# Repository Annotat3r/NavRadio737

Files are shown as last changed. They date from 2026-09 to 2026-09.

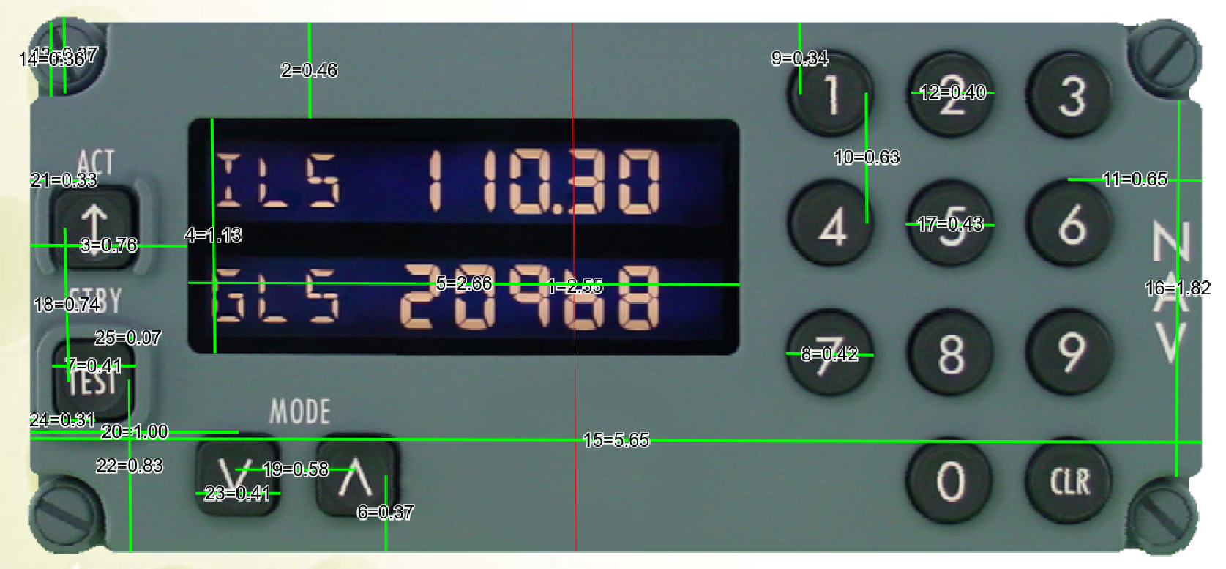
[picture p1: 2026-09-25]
CAD/References/Nav Panel Measured.png

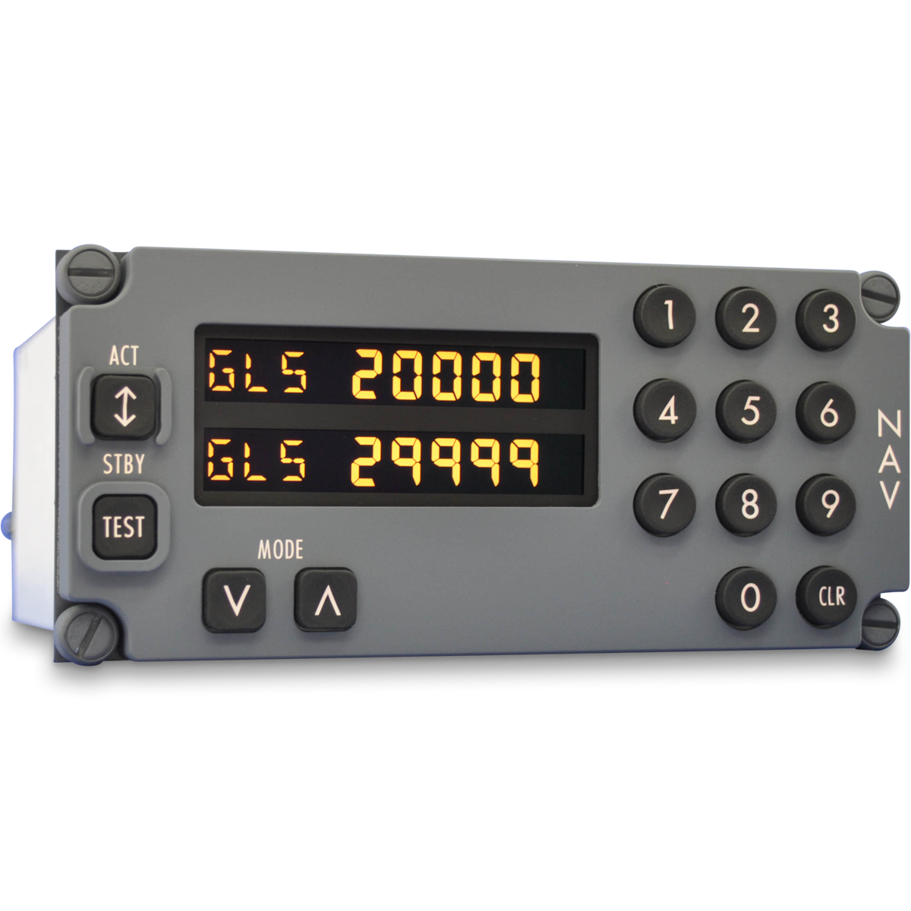
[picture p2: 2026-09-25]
CAD/References/Nav Radio 1.png

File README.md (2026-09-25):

MobiFlight Custom Device for the Boeing 737NG Multi-Mode Radio (MMR)

developed by Ryan Goff from the MF Community Device Template. It is

based on the Gables Engineering G7501-01 Boeing 737 Nav GLS Panel.

This project was developed for use with X-Plane 12 and the Zibo 

mod Boeing 737. The custom device code is written for the way 

X-Plane 12 outputs data for displaying on the LCD screen. I don't 

believe this code would work for MSFS without modifying.

CAD FILES

The CAD files include .stp (step) for all of the parts but it is important

to understand that I designed the parts with specific manufacturing

equipment in mind. The Acrylic and Plexiglass parts were cut using

a desktop cnc machine, spray painted, and then the text laser-engraved

using a blue-light diode laser.

The buttons were 3D printed using white filament, spray painted black,

and then laser engraved.

Because of the laser-engraving being a step that occurs later, the

CAD files for the faceplate and buttons do not include any text. The

text was added in the laser engraving software.

I have included 737NavRadio\_PCBA.step, which is a step file export of

the custom printed circuit board assembly.

PCBA

The PCBA features an on-board Raspberry Pi Pico (RP2040), making this

a fully self-contained device that requires no additional connections

to external microcontroller devices.

The backlighting is designed to operate off of an external 12V DC power

supply and does not work if only connected to 5V USB. If you are building

this panel and don't have, and don't want to acquire an external 12V

power supply, you will need to make edits to the schematic and board

files. Powering the backlighting from an external 12V source was done

to reduce the overall current requirements of the PCBA vs. powering

them from 5V. The backlighting is fully dimmable via connection to one

GPIO PWM pin through an N-Channel MOSFET.

Nearly all surface-mount devices on the PCB were ordered as part of the

PCB Assembly via jlcpcb.com. Through-hole components such as the 12V

power connection, the USB-Micro connector, 2-pin header for bootsel,

and 4-pin header for connecting the OLED display are user-soldered. All

push-buttons and LEDs on the PCB are user-soldered, though these are

SMT components.

The OLED display purchased must be a 2.42" 128x64 OLED LCD with I2C and

SSD1309 driver. The specific device I used in my build was from AliExpress

TZT 123 Official Store:

https://www.aliexpress.us/item/3256802580414312.html

Download the NavRadio737 custom device and move it to your MF Community

folder directory. Use the RP2040 pin connections shown in the schematic

to set up your mobiflight input/output devices.

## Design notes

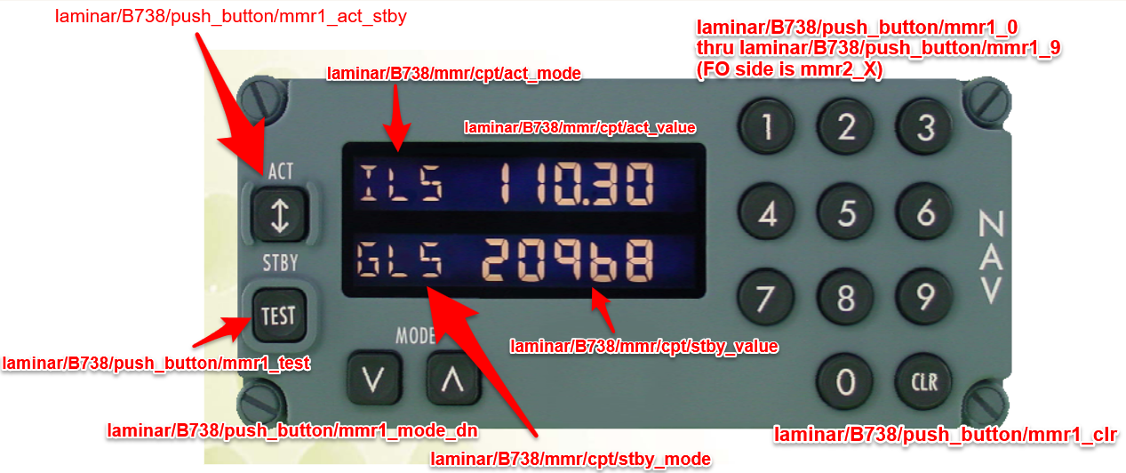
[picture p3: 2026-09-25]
CAD/References/Nav Radio Datarefs.png

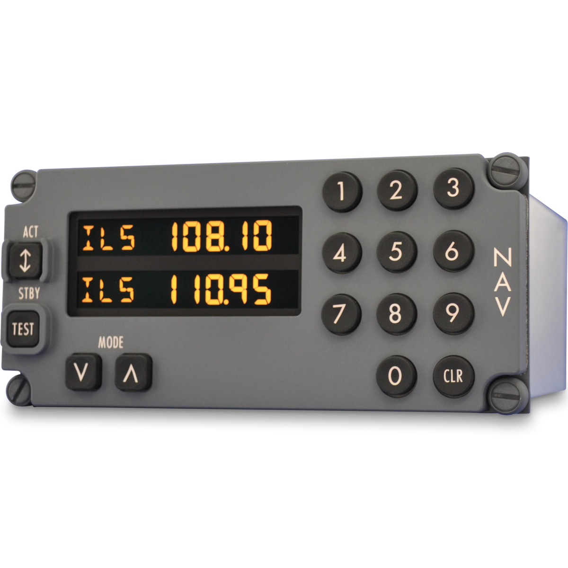
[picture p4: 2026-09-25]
CAD/References/Nav Radio 2.png

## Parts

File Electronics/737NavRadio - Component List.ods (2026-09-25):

Reference | Value | Source & Part Number | Footprint | Qty
C1,C5 | 33pF | https://www.lcsc.com – C1663, 33pF ceramic capacitor, 50V, 0603 SMT | PCM_JLCPCB:C_0603 | 2
C2,C3,C6,C7,C8,C9,C10,C11,C12,C13,C17 | 100nF | https://www.lcsc.com - C307331, 100nF ceramic capacitor, 50V, 0402 SMT | PCM_JLCPCB:C_0402 | 11
C4,C14 | 1uF | https://www.lcsc.com - C52923, 1uF ceramic capacitor, 25V, 0402 SMT | PCM_JLCPCB:C_0402 | 2
C15,C16 | 10uF | https://www.lcsc.com - C96446, 10uF ceramic capacitor, 25V, 0603 SMT | PCM_JLCPCB:C_0603 | 2
D1,D2 | SS14 | https://www.lcsc.com - C2480, 40V Schottky Diode DO-214AC | PCM_JLCPCB:D_SMA | 2
D3,D4,D5,D6,D7,D8,D9,D10,D11,D12,D13,D14,D15,D16,D17,D18,D19,D20,D21,D22 | 2.0Vf, 20mA If | Www.digikey.com - Würth Elektronik, 150080AS75000, LED AMBER CLEAR 0805 SMD | LED_SMD:LED_0805_2012Metric | 20
J1 | Conn_01x02 | www.digikey.com - PRPC002SAAN-RC, vertical connector header, 2.54mm pitch | Connector_PinHeader_2.54mm:PinHeader_1x02_P2.54mm_Vertical | 1
J2 | USB3131-30-0230-A | Www.digikey.com - USB3131-30-0230-A, micro B USB connector | SamacSys_Parts:CONN_USB3131-30-0230-A_GCT | 1
J3 |  | www.digikey.com - B2B-XH-A, 2.54mm JST connector | SamacSys_Parts:JST_B2B-XH-A | 1
J4,J5,J6,J7,J8,J9,J10,J11,J12,J13,J14,J15,J16,J17,J18 |  | www.digikey.com - KSC241J LFS, tactile switches | KSC241JDCTLFS | 15
J19 | Conn_01x04_Pin | www.digikey.com - NRPN041PAEN-RC, vertical connector header, 2.54mm pitch | Connector_PinHeader_2.54mm:PinHeader_1x04_P2.54mm_Vertical | 1
Q1 | AO3400A | https://www.lcsc.com - C20917, MOSFET, N-Channel, 30V, SOT-23 | PCM_JLCPCB:Q_SOT-23 | 1
R1,R6 | 1kΩ | https://www.lcsc.com - C21190, 100mW, 0603 SMT | PCM_JLCPCB:R_0603 | 2
R2,R3 | 27Ω | https://www.lcsc.com - C25190, 100mW, 0603 SMT | PCM_JLCPCB:R_0603 | 2
R4 | 1k | https://www.lcsc.com - C11702, 62.5mW, 0402 SMT | PCM_JLCPCB:R_0402 | 1
R5 | DNF | Do Not Fit (DNF), no device soldered here unless certain adverse device behavior exists (rare) | Resistor_SMD:R_0805_2012Metric | 1
R7 | 10kΩ | https://www.lcsc.com - C25804, 100mW, 0603 SMT | PCM_JLCPCB:R_0603 | 1
R8,R9,R10,R11 | 120Ω | https://www.lcsc.com - C22787, 100mW, 0603 SMT | PCM_JLCPCB:R_0603 | 4
U1 | RP2040 | https://www.lcsc.com - C2040, Raspberry Pi RP2040 MCU | PCM_JLCPCB:QFN-56-1EP_7x7mm_P0.4mm_EP3.2x3.2mm_ThermalVias | 1
U2 | W25Q128JVSIQ | https://www.lcsc.com - C97521, 128M-Bit Serial Flash Memory | PCM_JLCPCB:SOIC-8_L5.3-W5.3-P1.27-LS8.0-BL | 1
U3 | AMS1117 | https://www.lcsc.com - C6186, 1A LDO 3V Regulator | PCM_JLCPCB:SOT-223-3_L6.5-W3.4-P2.30-LS7.0-BR | 1
X1 | X322512MSB4SI | https://www.lcsc.com - C9002, 12MHz 20pF Crystal Oscillator | PCM_JLCPCB:CRYSTAL-SMD_4P-L3.2-W2.5-BL | 1

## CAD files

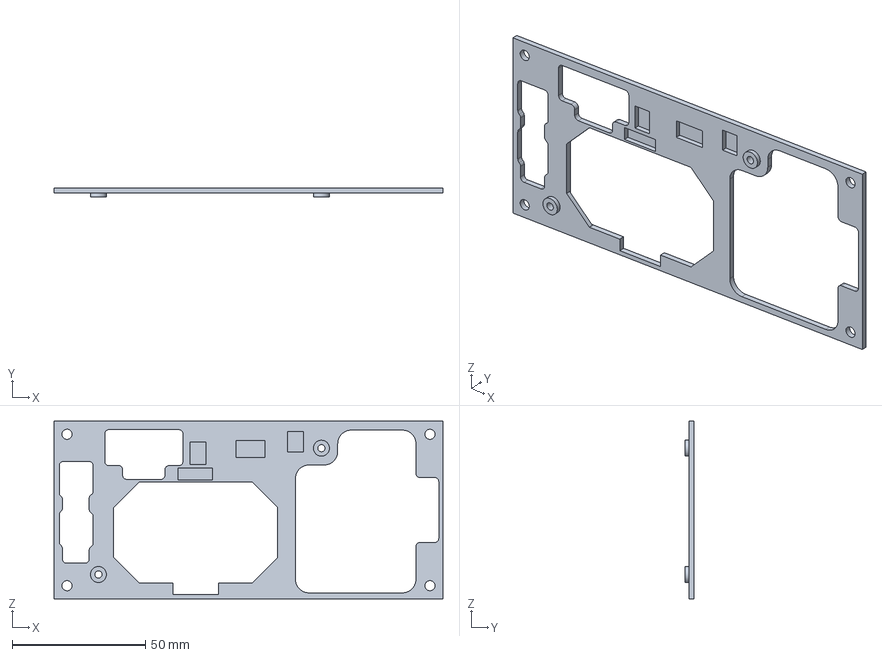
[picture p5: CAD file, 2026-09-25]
CAD/Nav Panel Backplate.stp
146.0 x 3.50 x 66.7 mm

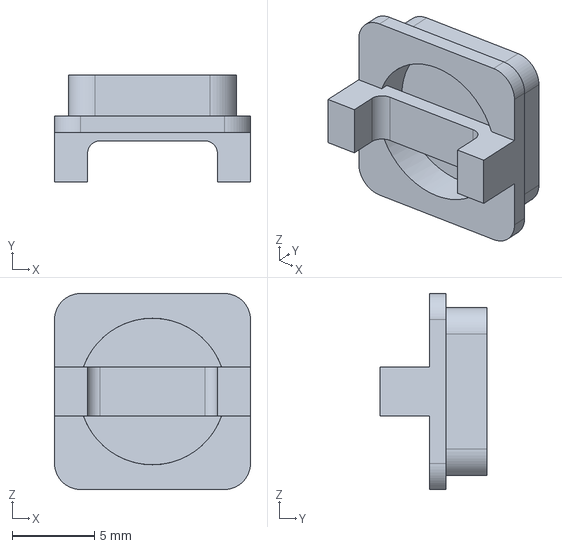
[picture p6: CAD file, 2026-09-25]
CAD/Square Button.stp
11.9 x 6.50 x 11.9 mm

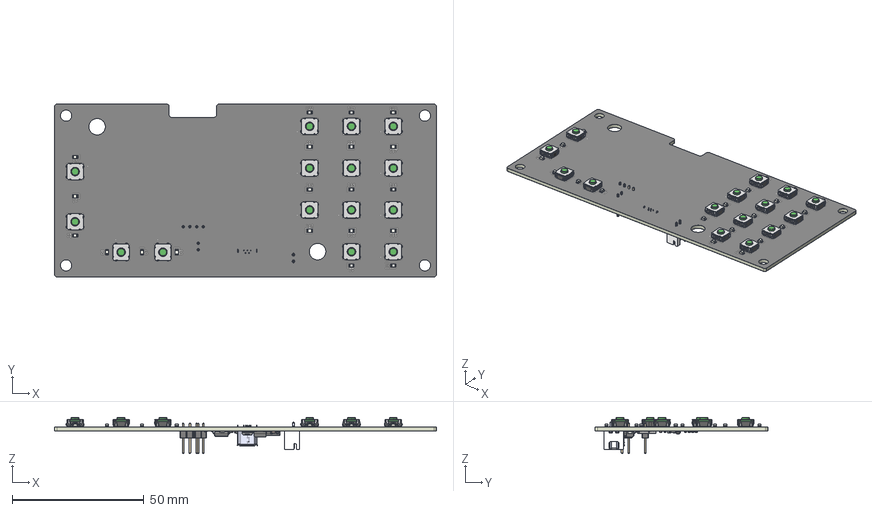
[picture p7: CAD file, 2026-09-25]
CAD/737NavRadio_PCBA.step
145.0 x 65.7 x 13.7 mm
KSC241J_DCT_LFS x 15
LED_0805_2012Metric x 20
C_0402 x 13
BxB-XH-A_02
PinHeader_1x04_P2.54mm_Vertical
R_0603 x 9
R_0805_2012Metric
PinHeader_1x02_P2.54mm_Vertical
C_0603 x 4
SOIC-8_L5.3-W5.3-P1.27-LS8.0-BL
SOT-223-3_L6.5-W3.4-P2.30-LS7.0-BR
Q_SOT-23
CRYSTAL-SMD_4P-L3.2-W2.5-BL
D_SMA x 2
R_0402
USB3131-30-0230-A
QFN-56-1EP_7x7mm_P0.4mm_EP3.2x3.2mm
737NavRadio_silkscreen x 2
737NavRadio_soldermask x 2
737NavRadio_PCB

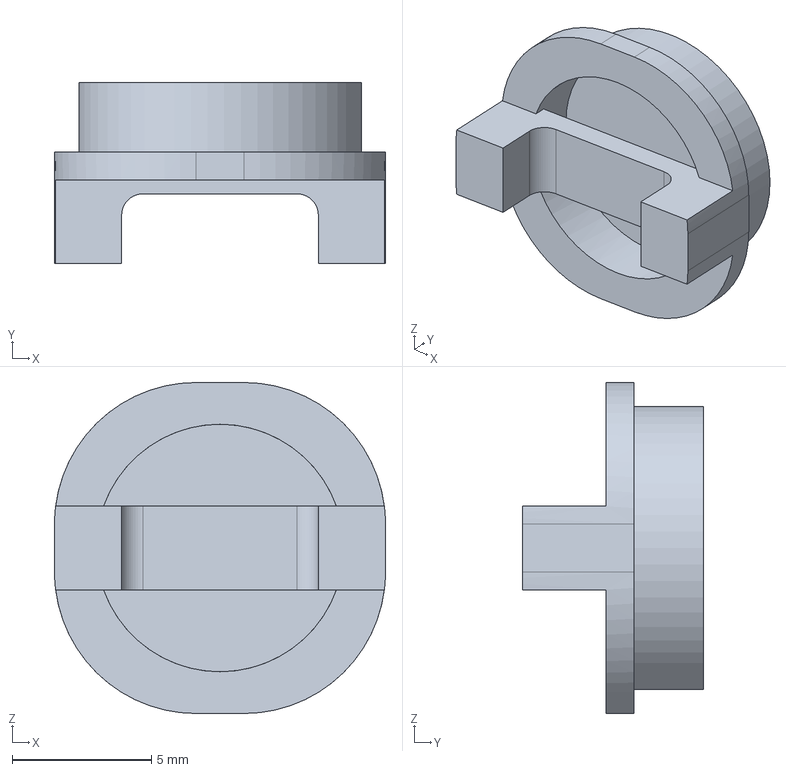
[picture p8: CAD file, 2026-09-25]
CAD/Round Button.stp
11.9 x 6.50 x 11.9 mm

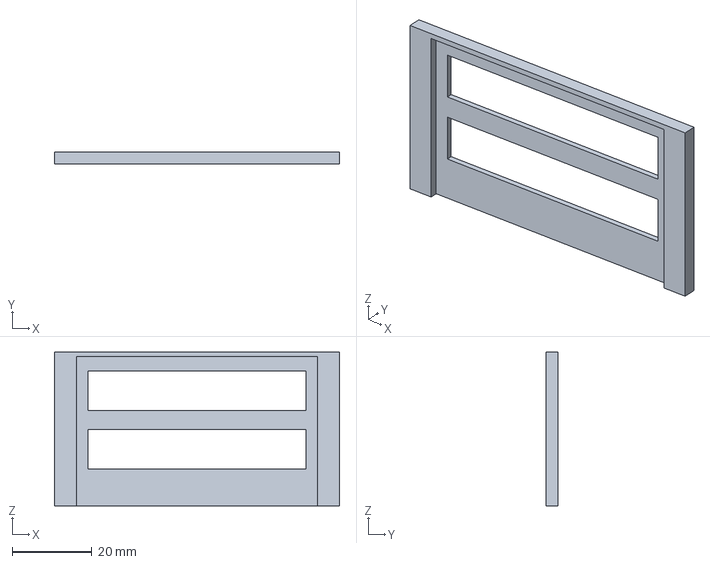
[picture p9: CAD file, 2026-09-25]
CAD/OLED Cover.stp
71.5 x 2.95 x 38.6 mm

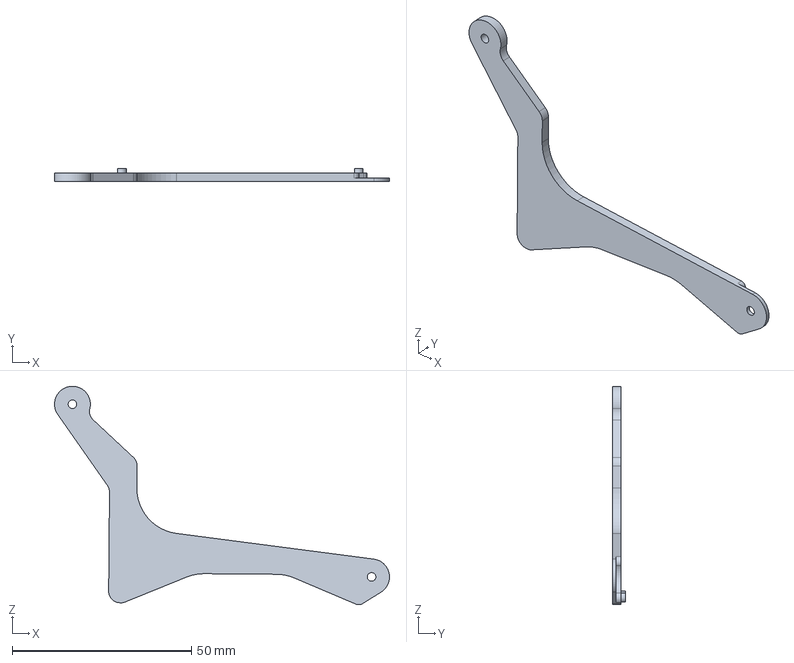
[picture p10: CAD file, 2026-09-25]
CAD/Main PCBA Washer.stp
93.3 x 3.75 x 60.9 mm

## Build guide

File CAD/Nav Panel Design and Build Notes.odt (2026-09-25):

Gables G7501-01 B737 Nav GLS Panel

https://www.gableseng.com/product/nav-gls-2/

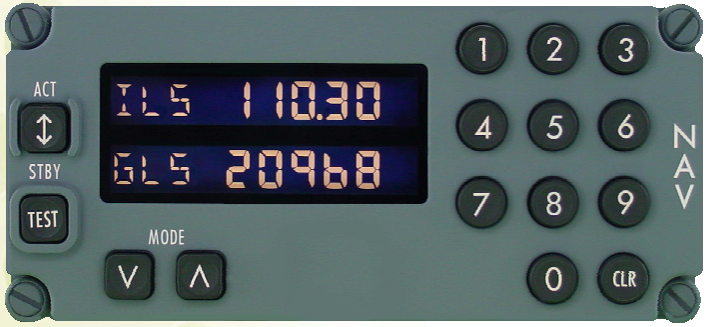
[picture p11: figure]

# Panel Sizing

Overall dimensions: 2.625” Height x 5.75” Wide (for the backplate). Based on the document “DZUS Rhythm” we know that the DSUZ fasteners are spaced in multiples of 3/8” (0.375”), so we can extrapolate that the fasteners here are at 2.25” apart center to center.

All panels in the center pedestal are 5.75” wide (width of the aluminum backplate).

The Faceplate typically is 1/32” smaller all the way around (1/16 overall), so 2.625 - .03125 Height x 5.75 - .03125 Wide. This comes out to a faceplate size of 2.59375” Height x 5.71875” Wide.

The center to center dimensions for the DZUS fasteners are 2.25” vertically, and 5.375” horizontally.

“Aluminum” backplate dimensions: 2.61” vertically, and 5.735” horizontally.

# The OLED Display

This 2.42” 128x64 OLED LCD SSD1309 Display (https://www.aliexpress.us/item/3256802580414312.html?curPageLogUid=d27N1Zjv7QwT) appears as though it would fit the display opening quite nicely. Here’s a screen grab of the dimensional information:

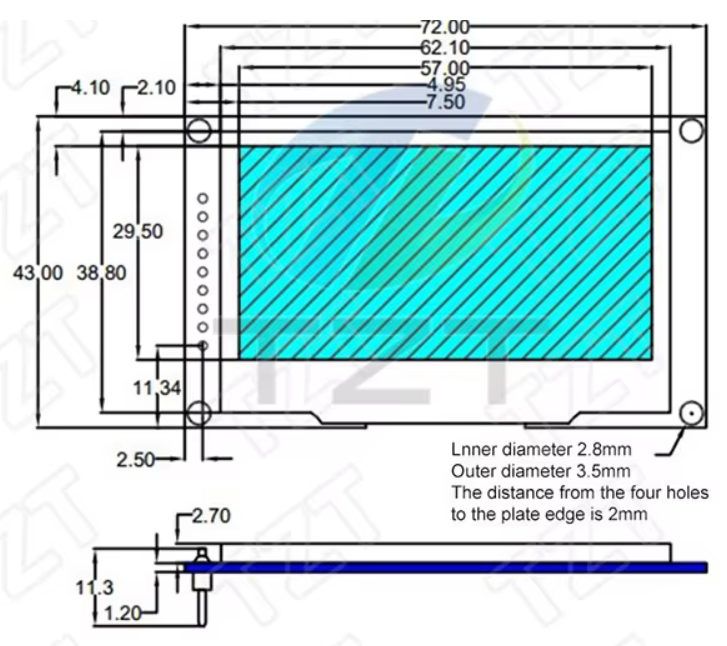
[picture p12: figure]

As can be seen, the display (viewable area) measures 2.244” wide x 1.16” tall. The discrepancies between the display size and the opening size can be filled with 3D printed bezel.

# Planning the Custom Device

In terms of a first custom device program, this one should be fairly easy.

I will need:

- A font that looks like 7-segment displays - Complete
- To create custom characters for the following: VOR, ILS, GLS, LVP
- On-board RP2040 design
- The only output is the display
- 15 button inputs.
- Ability for screen to go dark via MF sim dataref.
  - Maybe control screen power via another GPIO?
  - Maybe use the U8g2.setPowerSave(1) and (0) command?
  - This screen does not appear to support u8g2.setContrast(value).

## Simulator Integration

The nav radio in the zibo appears to be referred to as the “mmr”. Datarefs are tied to mmr.

laminar/B738/mmr/cpt/act_value for example is the dataref for the captain’s mmr active frequency value.

Datarefs below are untested:


## Code Considerations for Formatting the Display

### Active Frequency Formatting

ILS & VOR frequencies display a decimal point. GLS/LVP do not. Between VOR & ILS, the greatest frequency value is roughly 117.50Mhz. Specify formatting of sim value based on this. If statement, value greater than 12000 no decimal.

### Standby Frequency Display & Formatting

The dataref for the standby frequency displays the entries

## Display Information

The display I purchased uses I2C protocol.

Chip: SSD1309

4-Pin Connection
1 GND
2 VDD (3.3V)
3 SCL (Clock)
4 SDA (Data)

The address of the display appears to be 0x3C * 2, or 0x78 (in hex).

This is a 3.3V display. 128 x 64 pixels.

Each pixel is 0.4mm (0.0157”) square. The pitch of the pixels (distance from top of one pixel to top of next pixel) is 0.43mm (0.0169”).

If typical digit size for cockpit panels is 0.36”, my text height should be (.36” / .0169”) = 21 pixels. This actually works out to a digit height of .3549”. This will be a starting point and may need tweaked depending on visual preference.

Display “active” area is 55.02mm (2.166”) wide x 27.5mm (1.083”) tall.

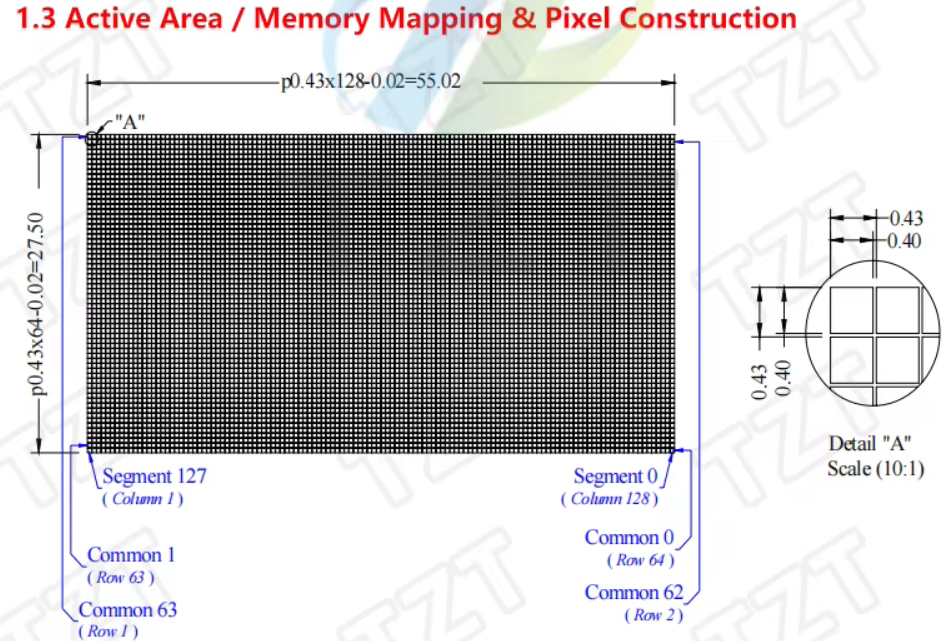
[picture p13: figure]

# The Code

## Helpful Notes for designing the Code

In the C++, note that calling out pins is referring to the GPIO number of the RP2040, NOT the actual device pin number! Example: Wire.setSDA(4); means SDA is connected to GPIO4, which is actually pin 6.

In the U8g2 library, text coordinates refer to the baseline (the bottom) of the text, not the top. If you draw at y = 0, your text will be off-screen. Usually, you start at y = 10 for the top line.

# Notes for the Electronics

Illuminated white tactile switches are aliexpress versions of the TS29-1212-1-WT-300-D switches by Same Sky. Vf = 3.2V typ. If = 20mA typ. Marked leg on LED is the cathode pin (short pin, negative).

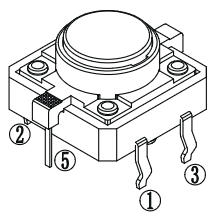
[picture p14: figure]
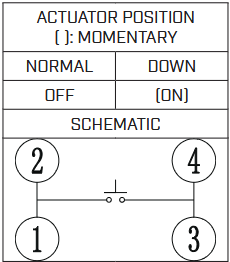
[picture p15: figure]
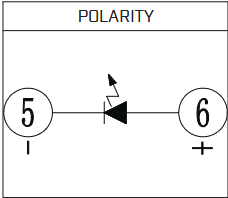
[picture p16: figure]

# Things Left To Do

Add 4-pin 2.54mm pitch header for connecting OLED to main PCBA. Determine what the connection method between these two boards will be.

Add mounting holes in PCB to attach to panel back plate.

Determine LEDs for the minimal backlighting of panel text.

Find a solution to opening in back plate behind the “MODE” text.

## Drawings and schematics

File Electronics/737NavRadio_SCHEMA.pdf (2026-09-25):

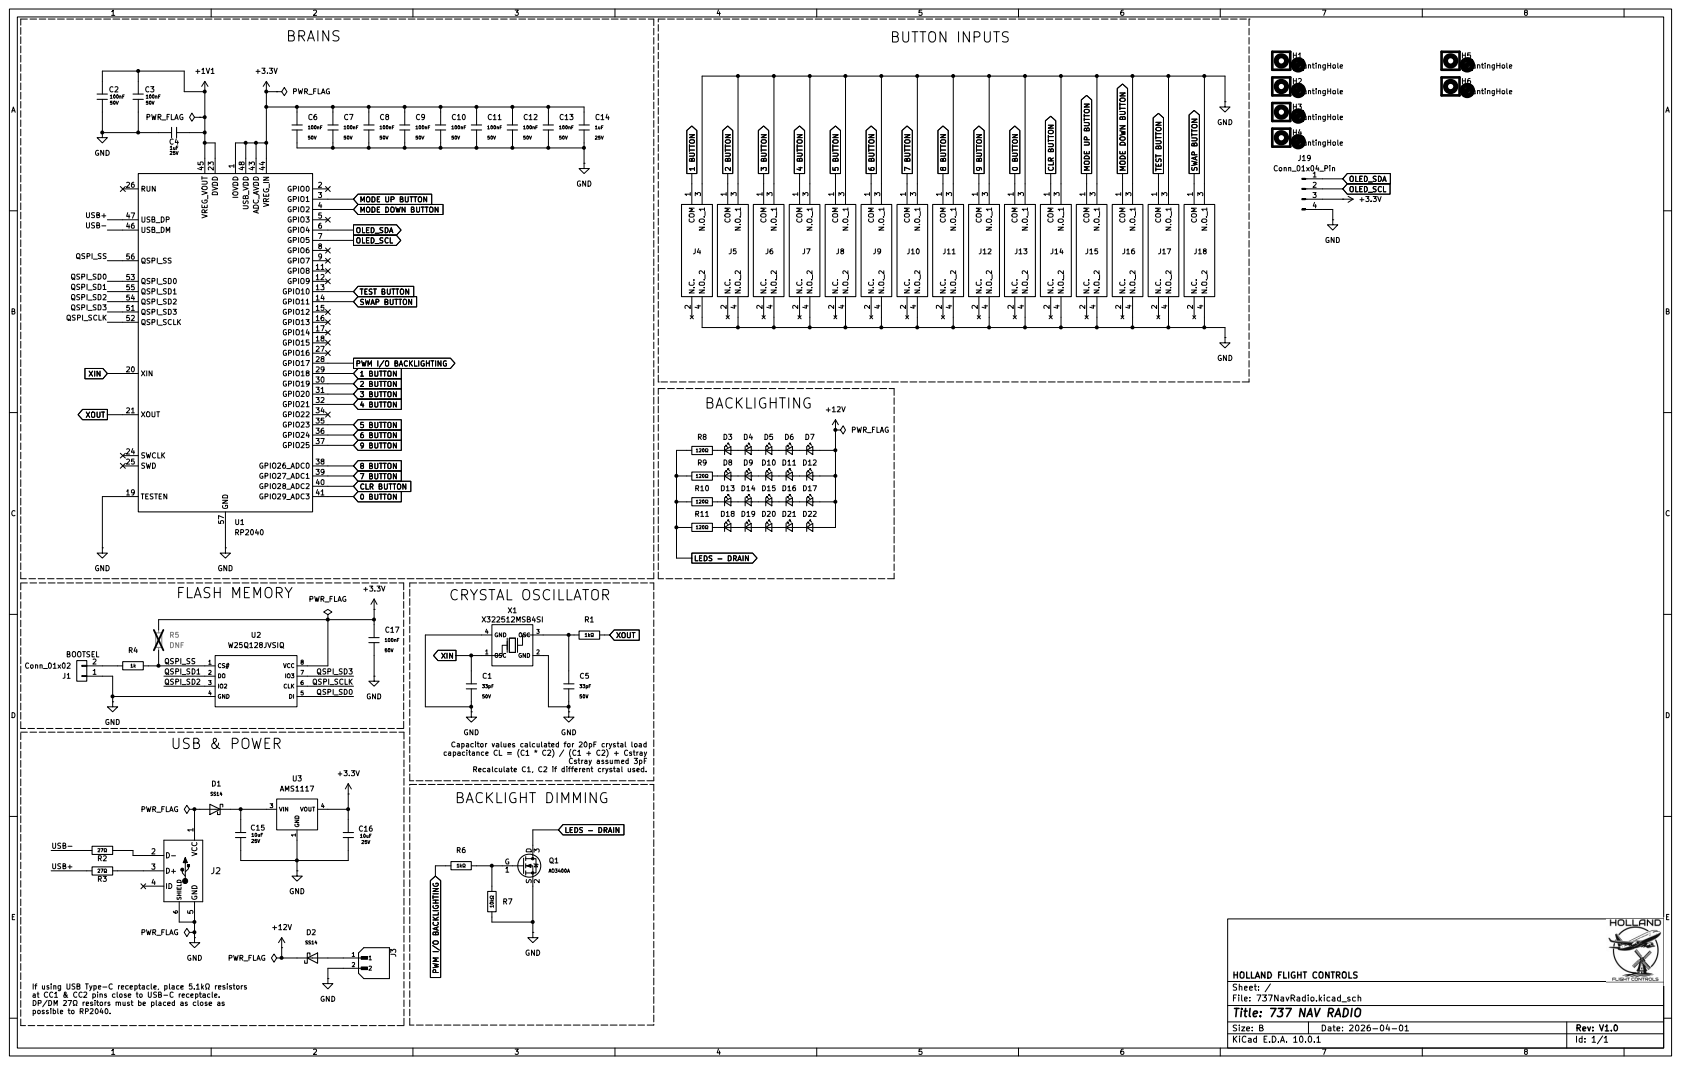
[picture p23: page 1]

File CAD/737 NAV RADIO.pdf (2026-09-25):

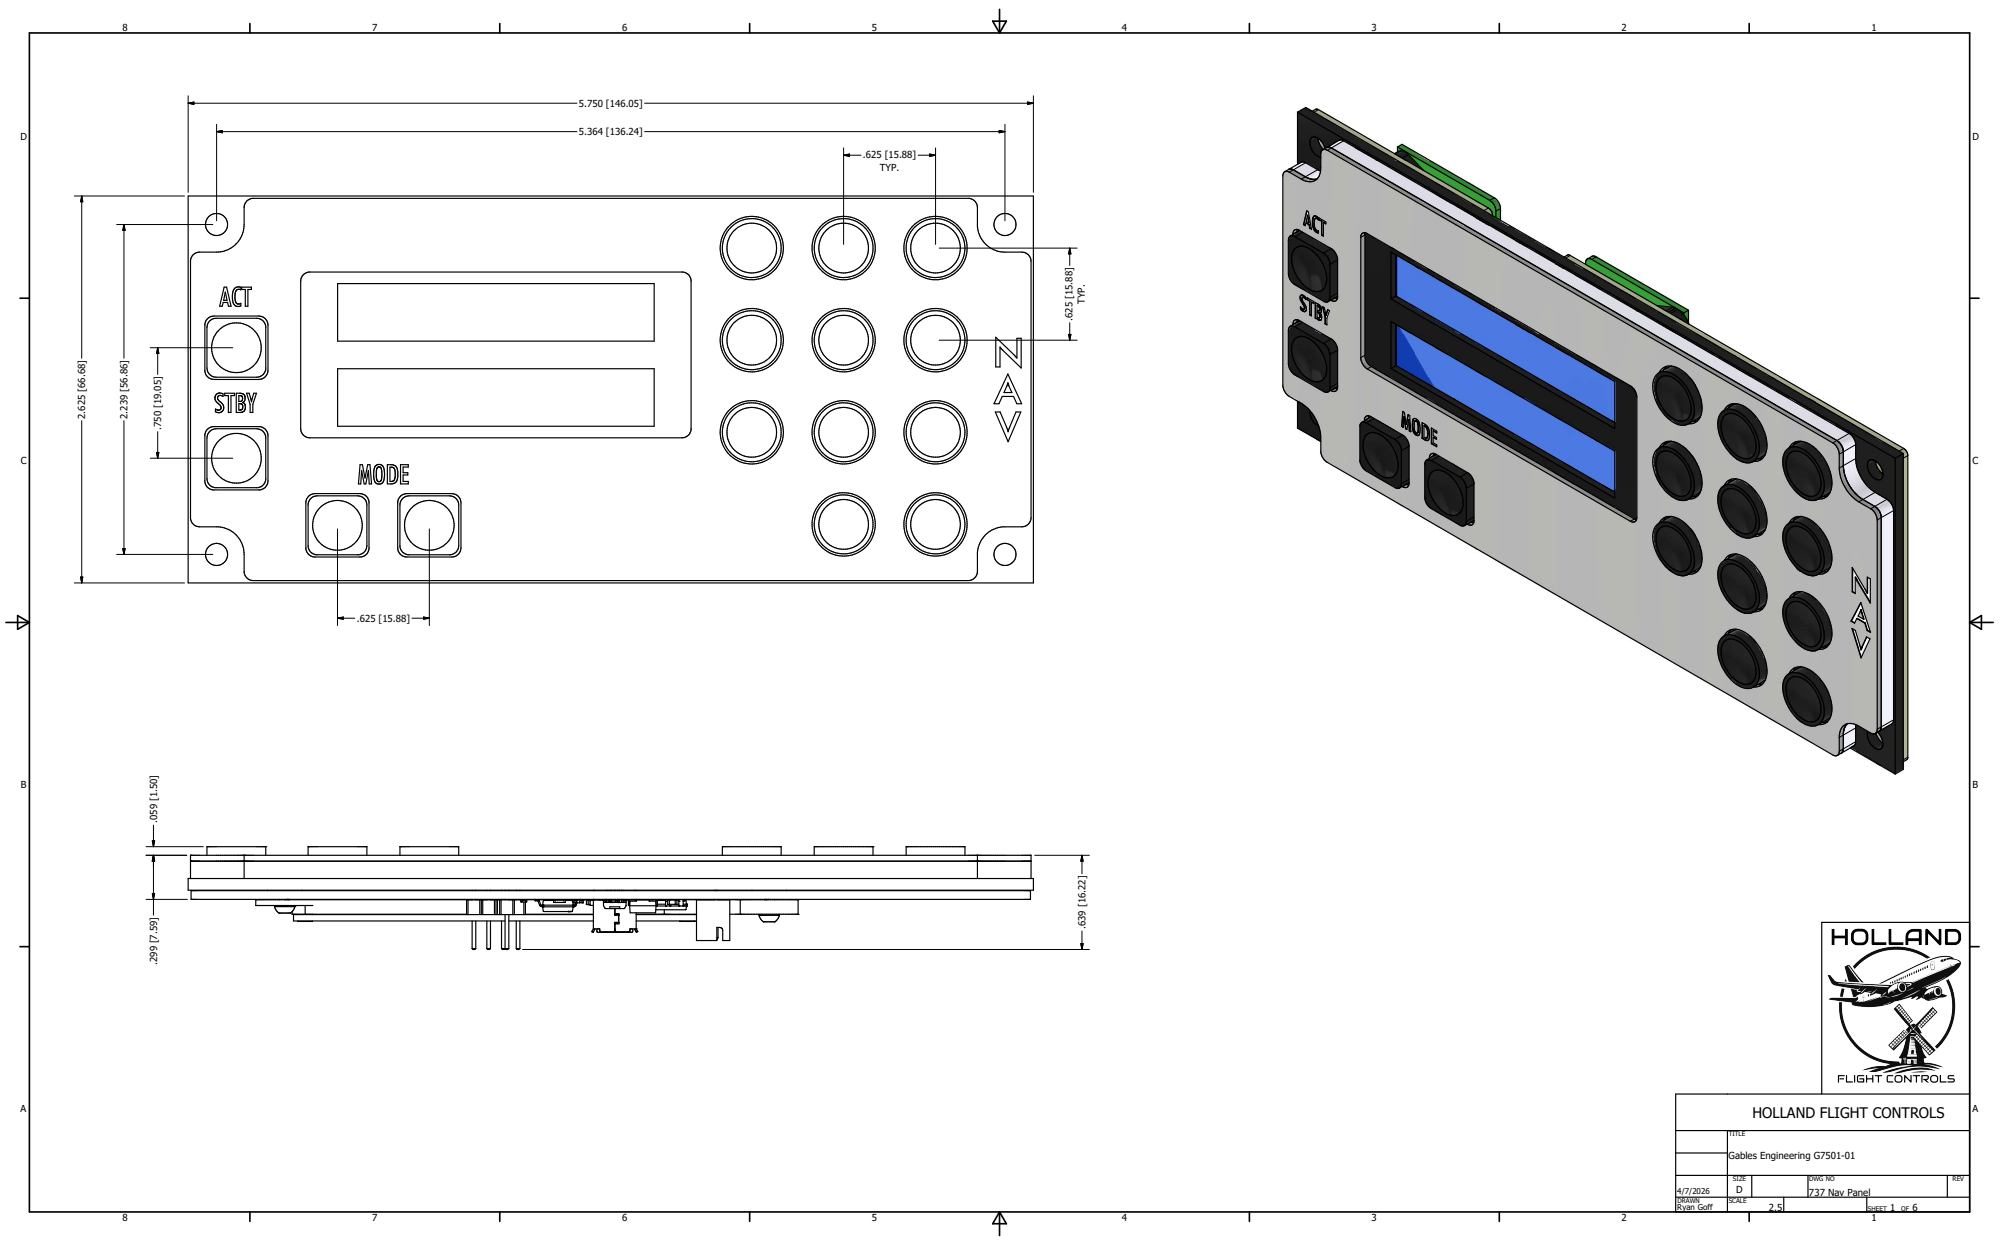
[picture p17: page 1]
DRAWN Ryan Goff; SCALE; DWG NO; 737 Nav Panel; REV; SHEET 1 OF 6 ².625 [66.68]; .625 [15.88] TYP.; .625 [15.88] TYP. .299 [7.59] .059 [1.50]

HOLLAND FLIGHT CONTROLS TITLE Gables Engineering G7501-01 SIZE D

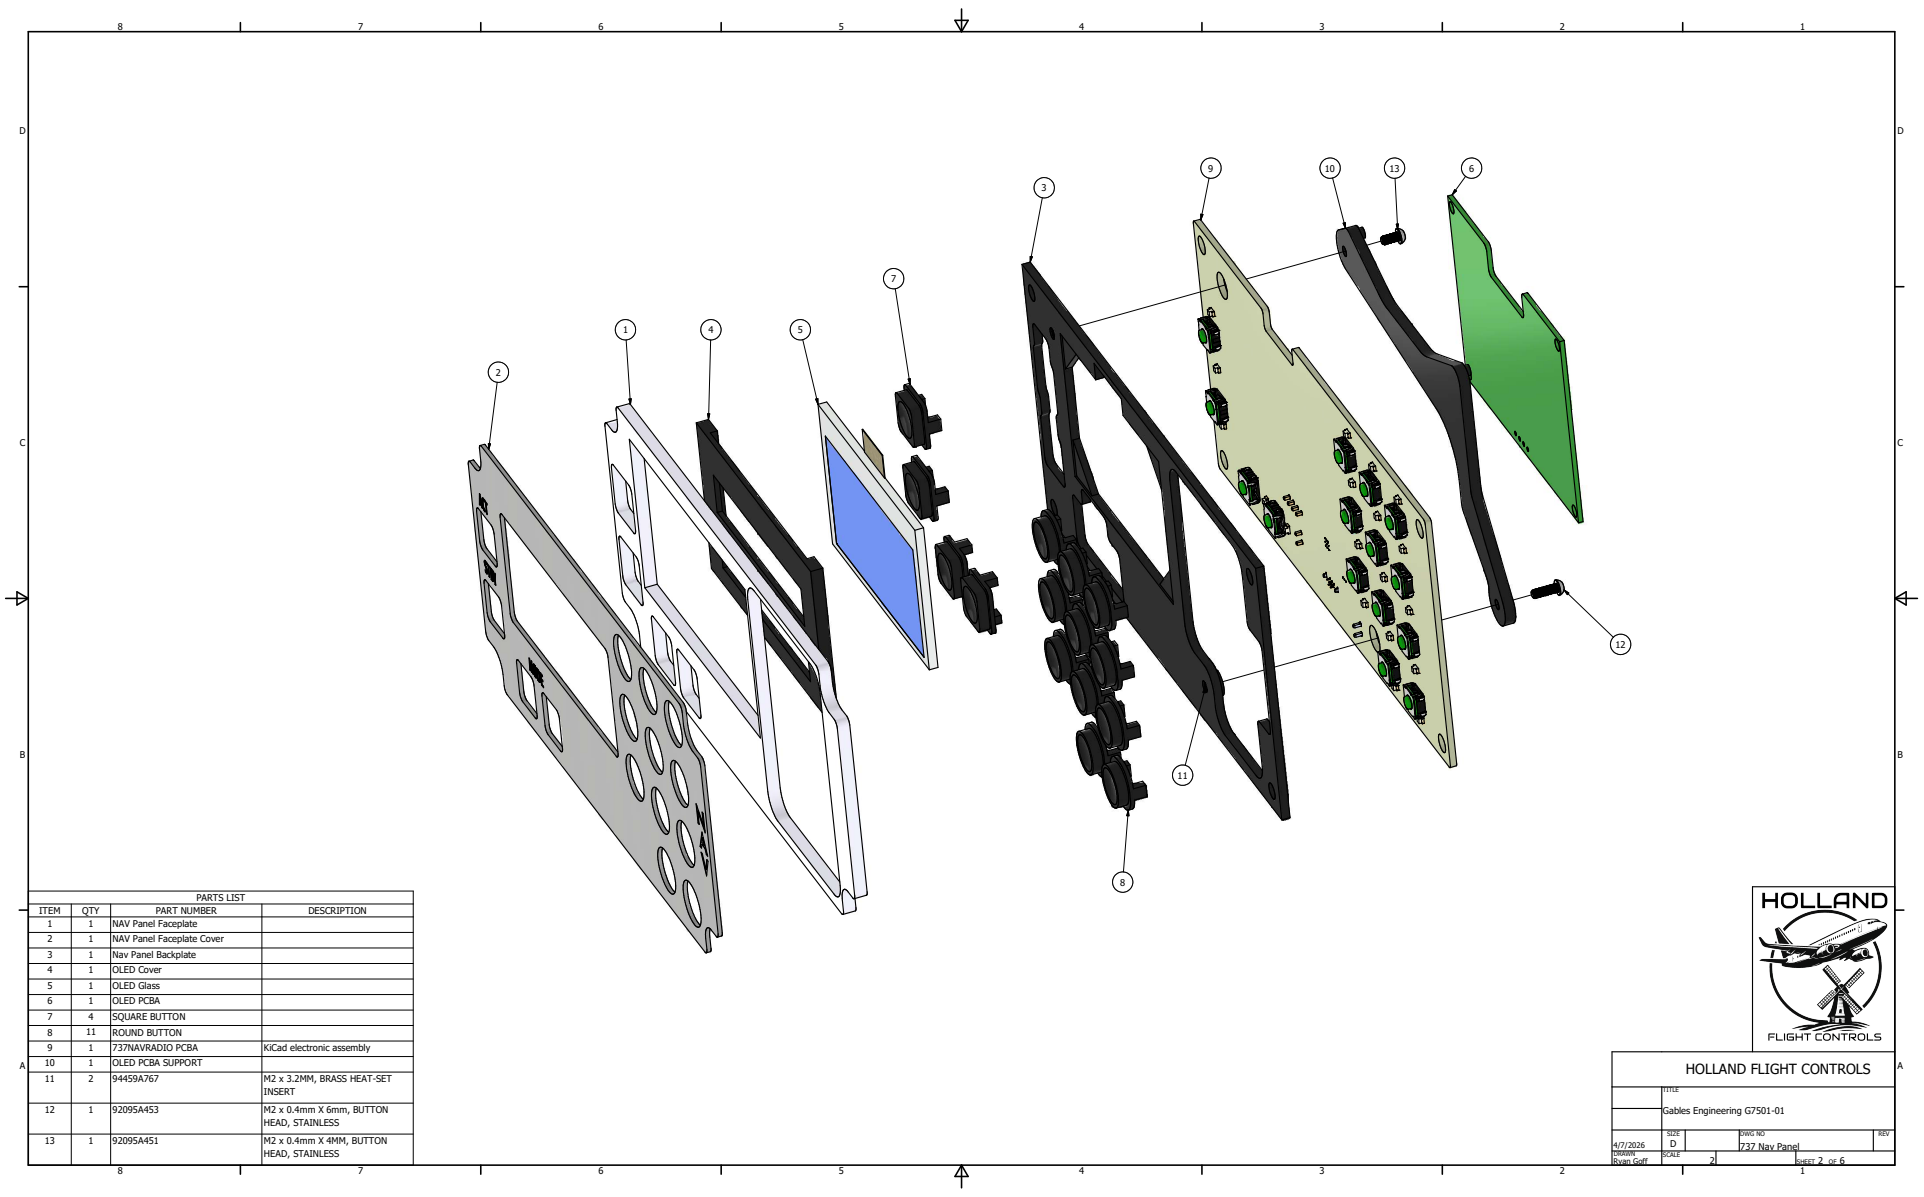
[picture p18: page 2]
2 SHEET 2 OF 6; PARTS LIST; ITEM; QTY; PART NUMBER; DESCRIPTION; NAV Panel Faceplate 2; NAV Panel Faceplate Cover; Nav Panel Backplate 4; OLED Cover 5; OLED Glass; OLED PCBA; SQUARE BUTTON; ROUND BUTTON; 737NAVRADIO PCBA; KiCad electronic assembly; OLED PCBA SUPPORT

HOLLAND FLIGHT CONTROLS TITLE Gables Engineering G7501-01 SIZE D

M2 x 3.2MM, BRASS HEAT-SET
INSERT
M2 x 0.4mm X 6mm, BUTTON
HEAD, STAINLESS
M2 x 0.4mm X 4MM, BUTTON

# HEAT PRESS THREADED BRASS INSERTS INTO

REAR OF BACKPLATE, (2) PLCS. | ASSEMBLY OF THE NAVIGATION RADIO REQUIRES

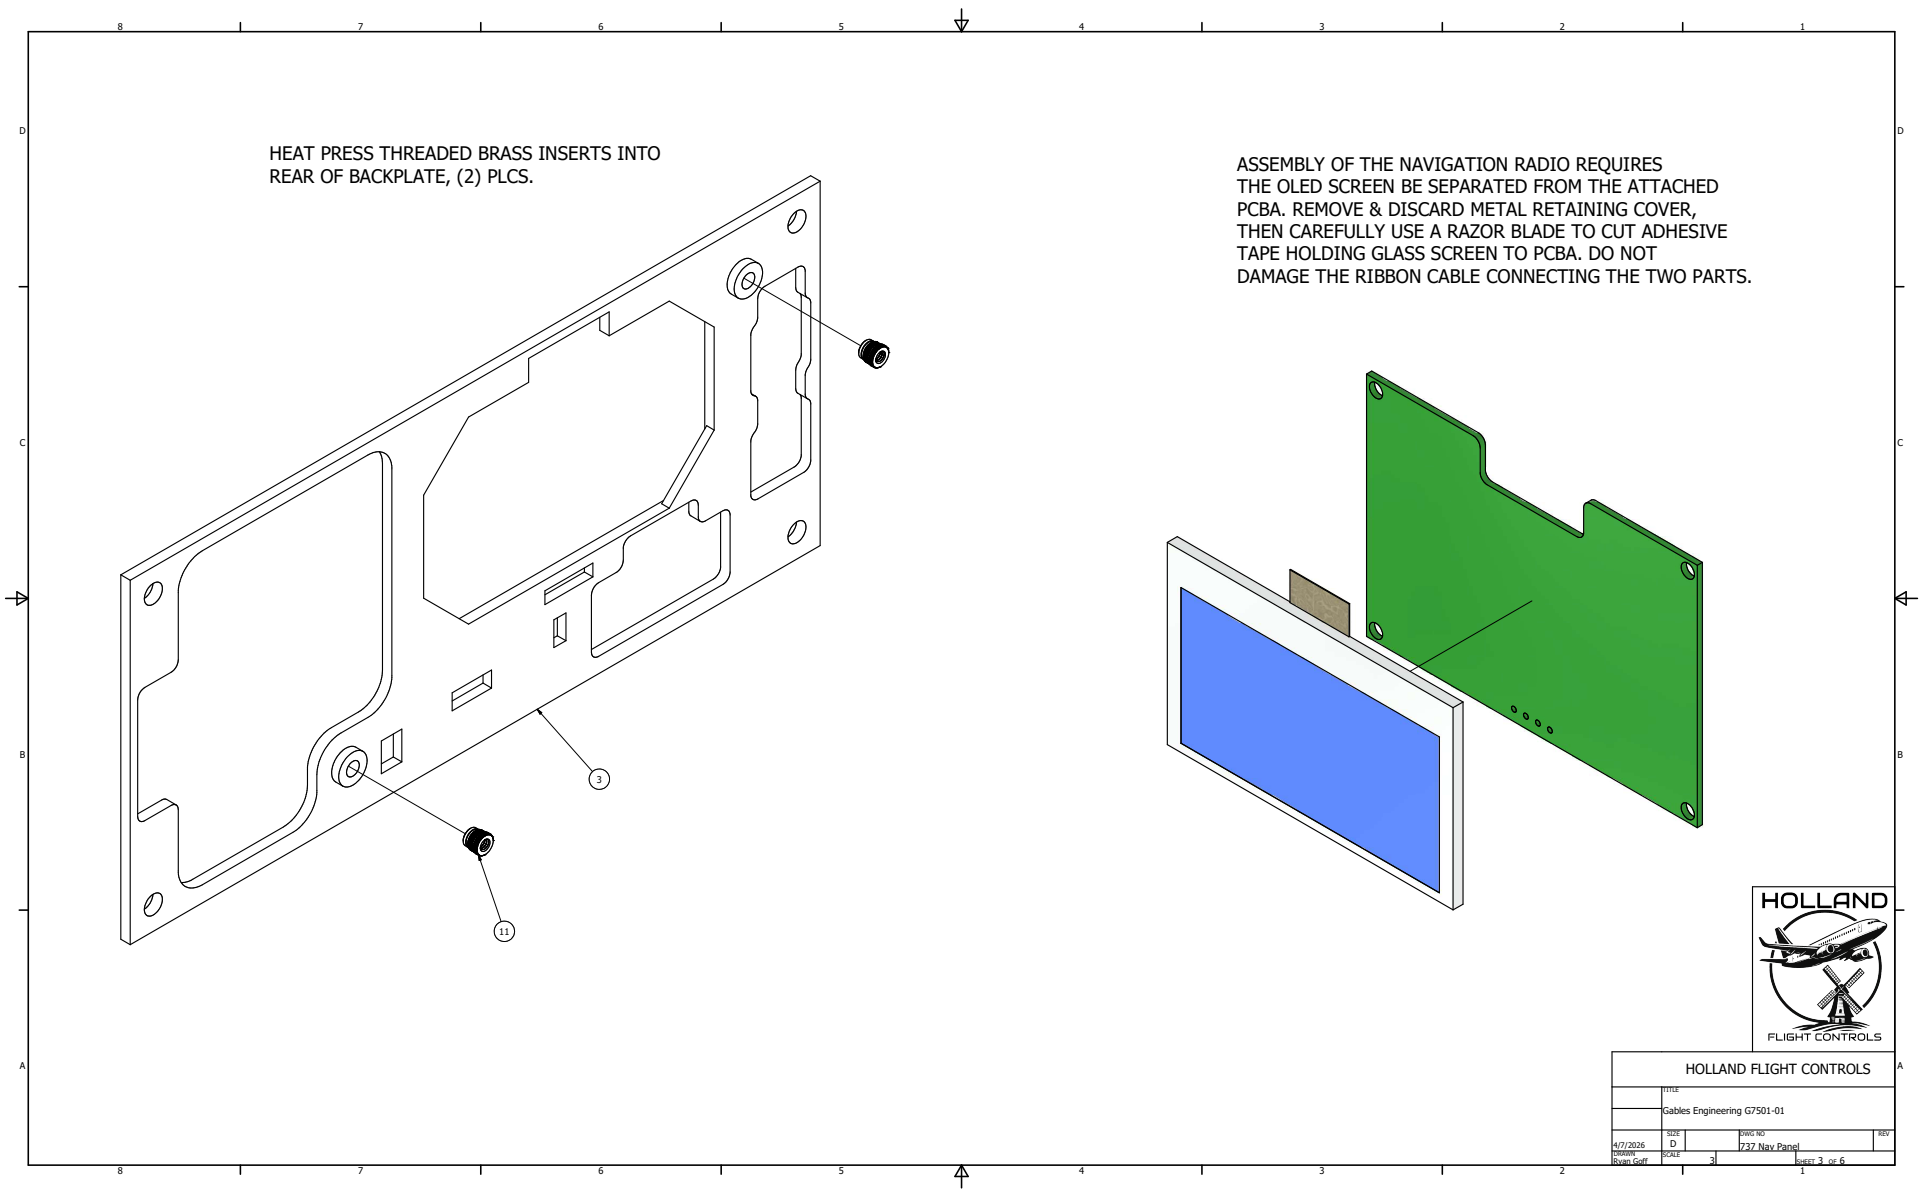
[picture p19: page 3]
3 SHEET 3 OF 6

THE OLED SCREEN BE SEPARATED FROM THE ATTACHED
PCBA. REMOVE & DISCARD METAL RETAINING COVER,
THEN CAREFULLY USE A RAZOR BLADE TO CUT ADHESIVE
TAPE HOLDING GLASS SCREEN TO PCBA. DO NOT
DAMAGE THE RIBBON CABLE CONNECTING THE TWO PARTS.

HOLLAND FLIGHT CONTROLS TITLE Gables Engineering G7501-01 SIZE D

# GLUE FACEPLATE COVER, FACEPLATE & BACK PLATE TOGETHER AFTER

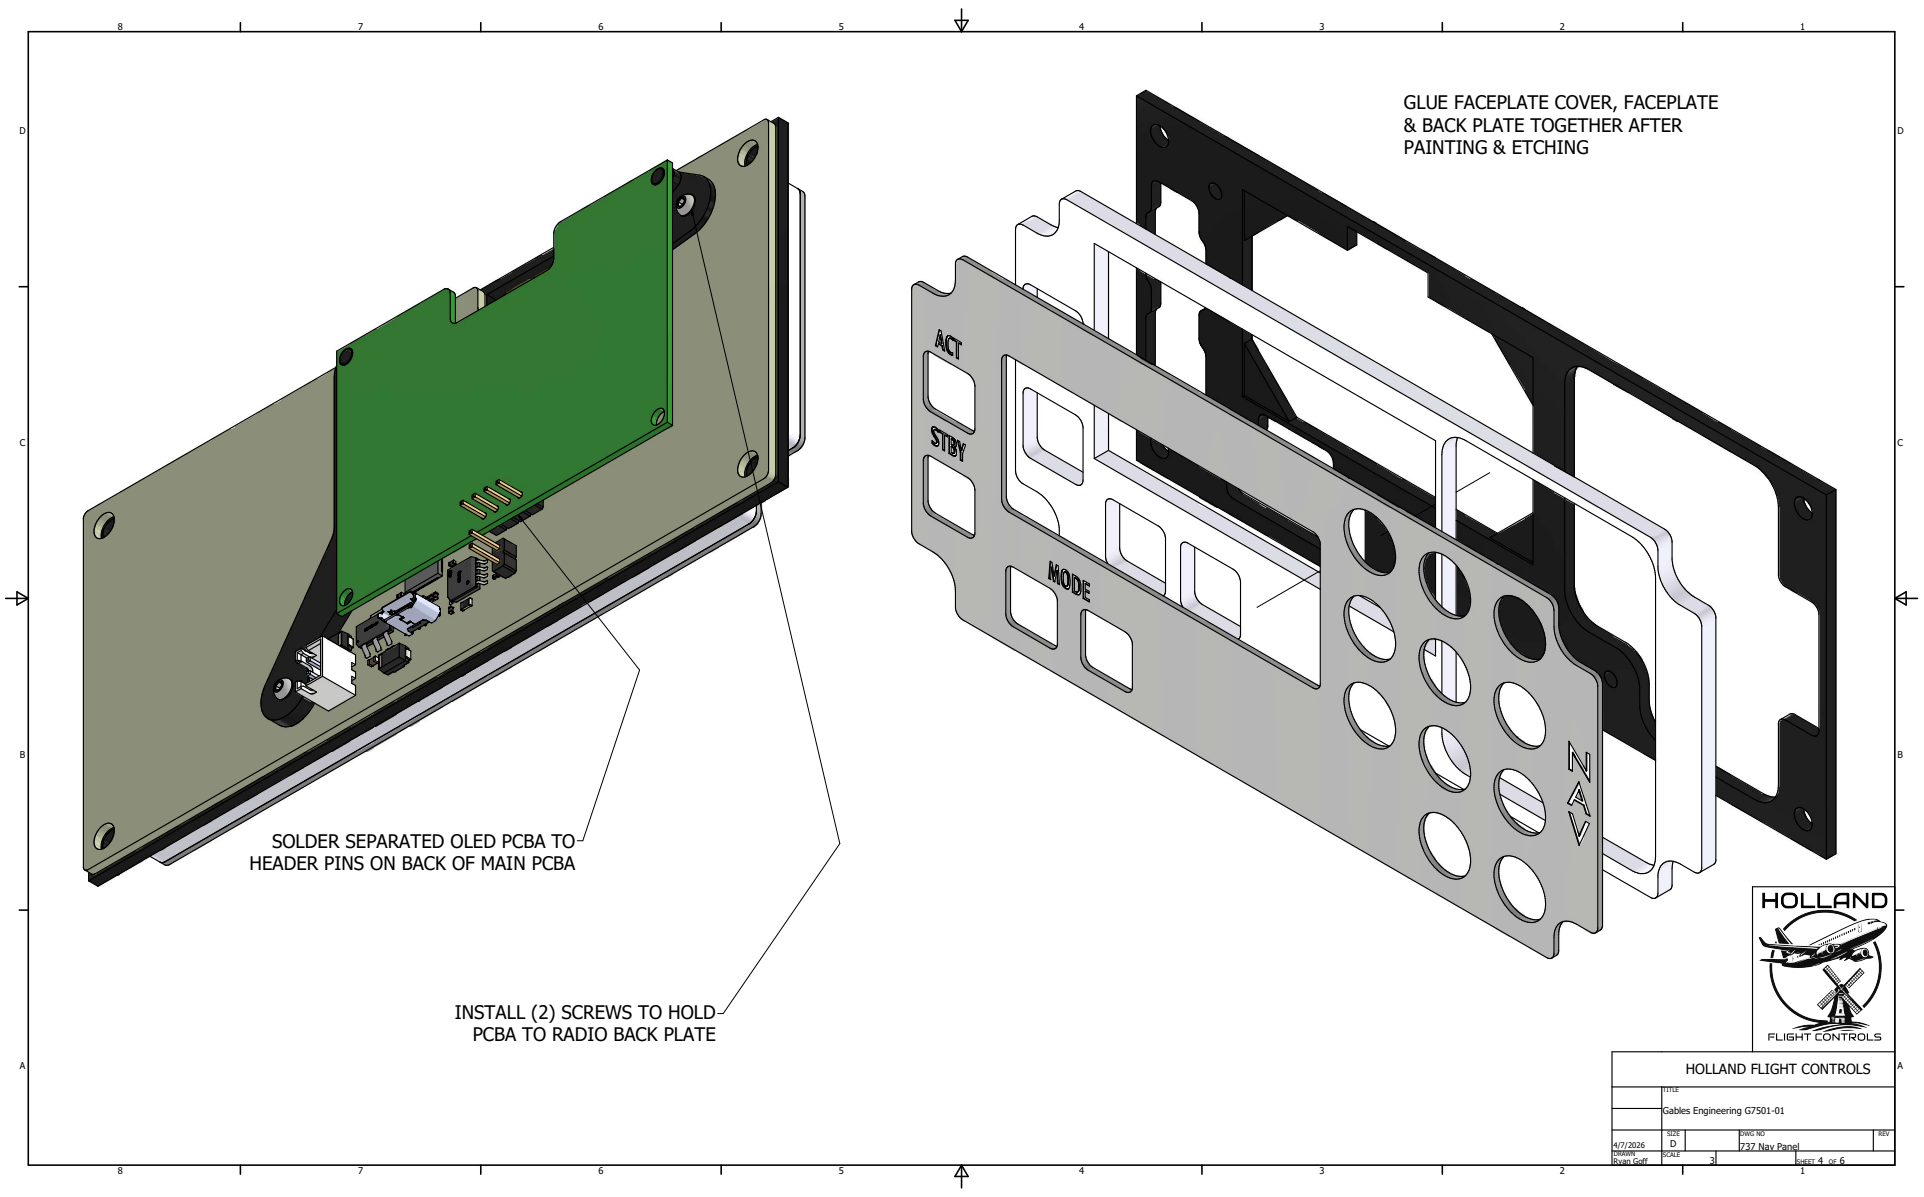
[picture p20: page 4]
3 SHEET 4 OF 6; PAINTING & ETCHING

SOLDER SEPARATED OLED PCBA TO
HEADER PINS ON BACK OF MAIN PCBA

INSTALL (2) SCREWS TO HOLD
PCBA TO RADIO BACK PLATE

HOLLAND FLIGHT CONTROLS TITLE Gables Engineering G7501-01 SIZE D

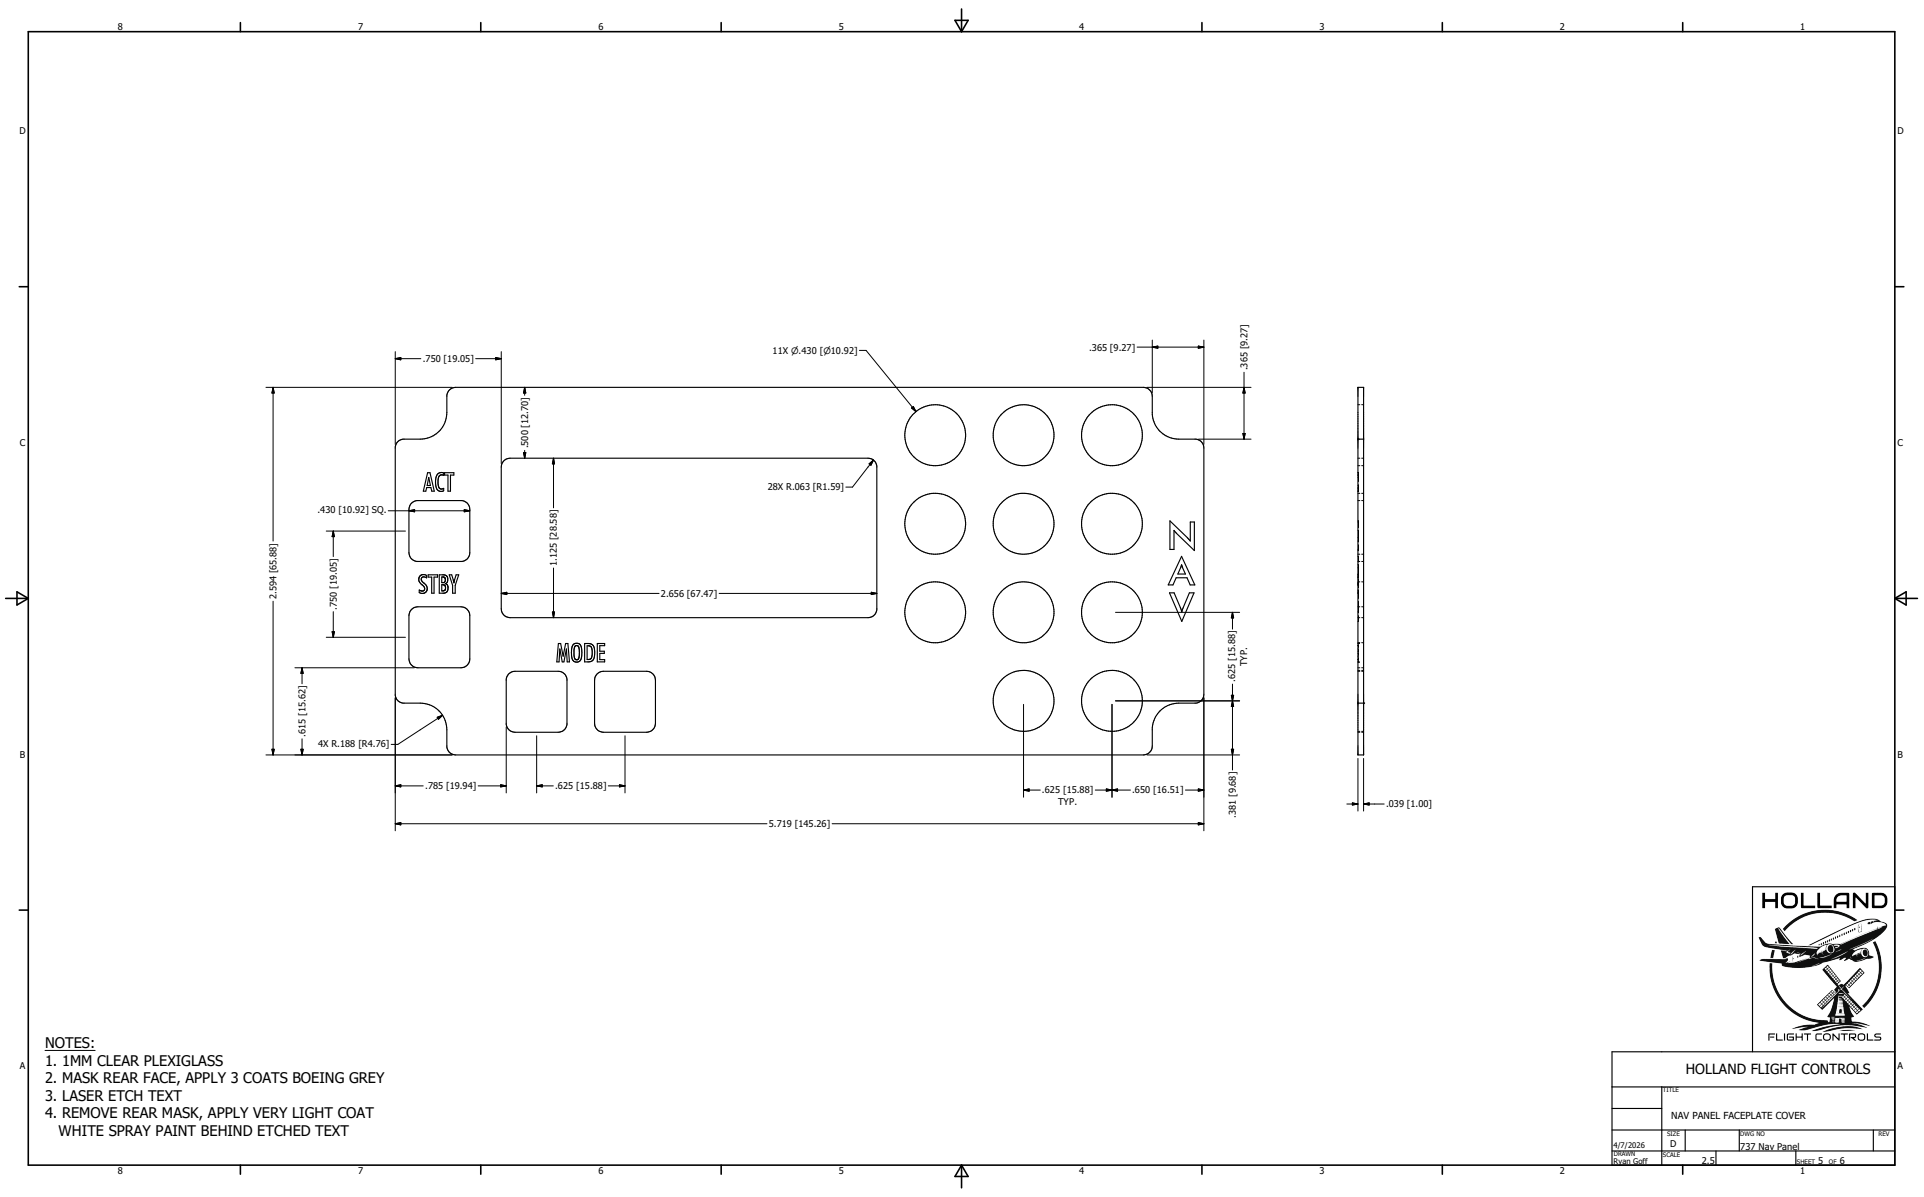
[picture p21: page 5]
.381 [9.68] .625 [15.88] TYP.; .650 [16.51] TYP. ².594 [65.88]

NOTES:
1. 1MM CLEAR PLEXIGLASS
2. MASK REAR FACE, APPLY 3 COATS BOEING GREY
3. LASER ETCH TEXT
4. REMOVE REAR MASK, APPLY VERY LIGHT COAT
WHITE SPRAY PAINT BEHIND ETCHED TEXT

HOLLAND FLIGHT CONTROLS TITLE

NAV PANEL FACEPLATE COVER

SIZE D

2.5 SHEET 5 OF 6

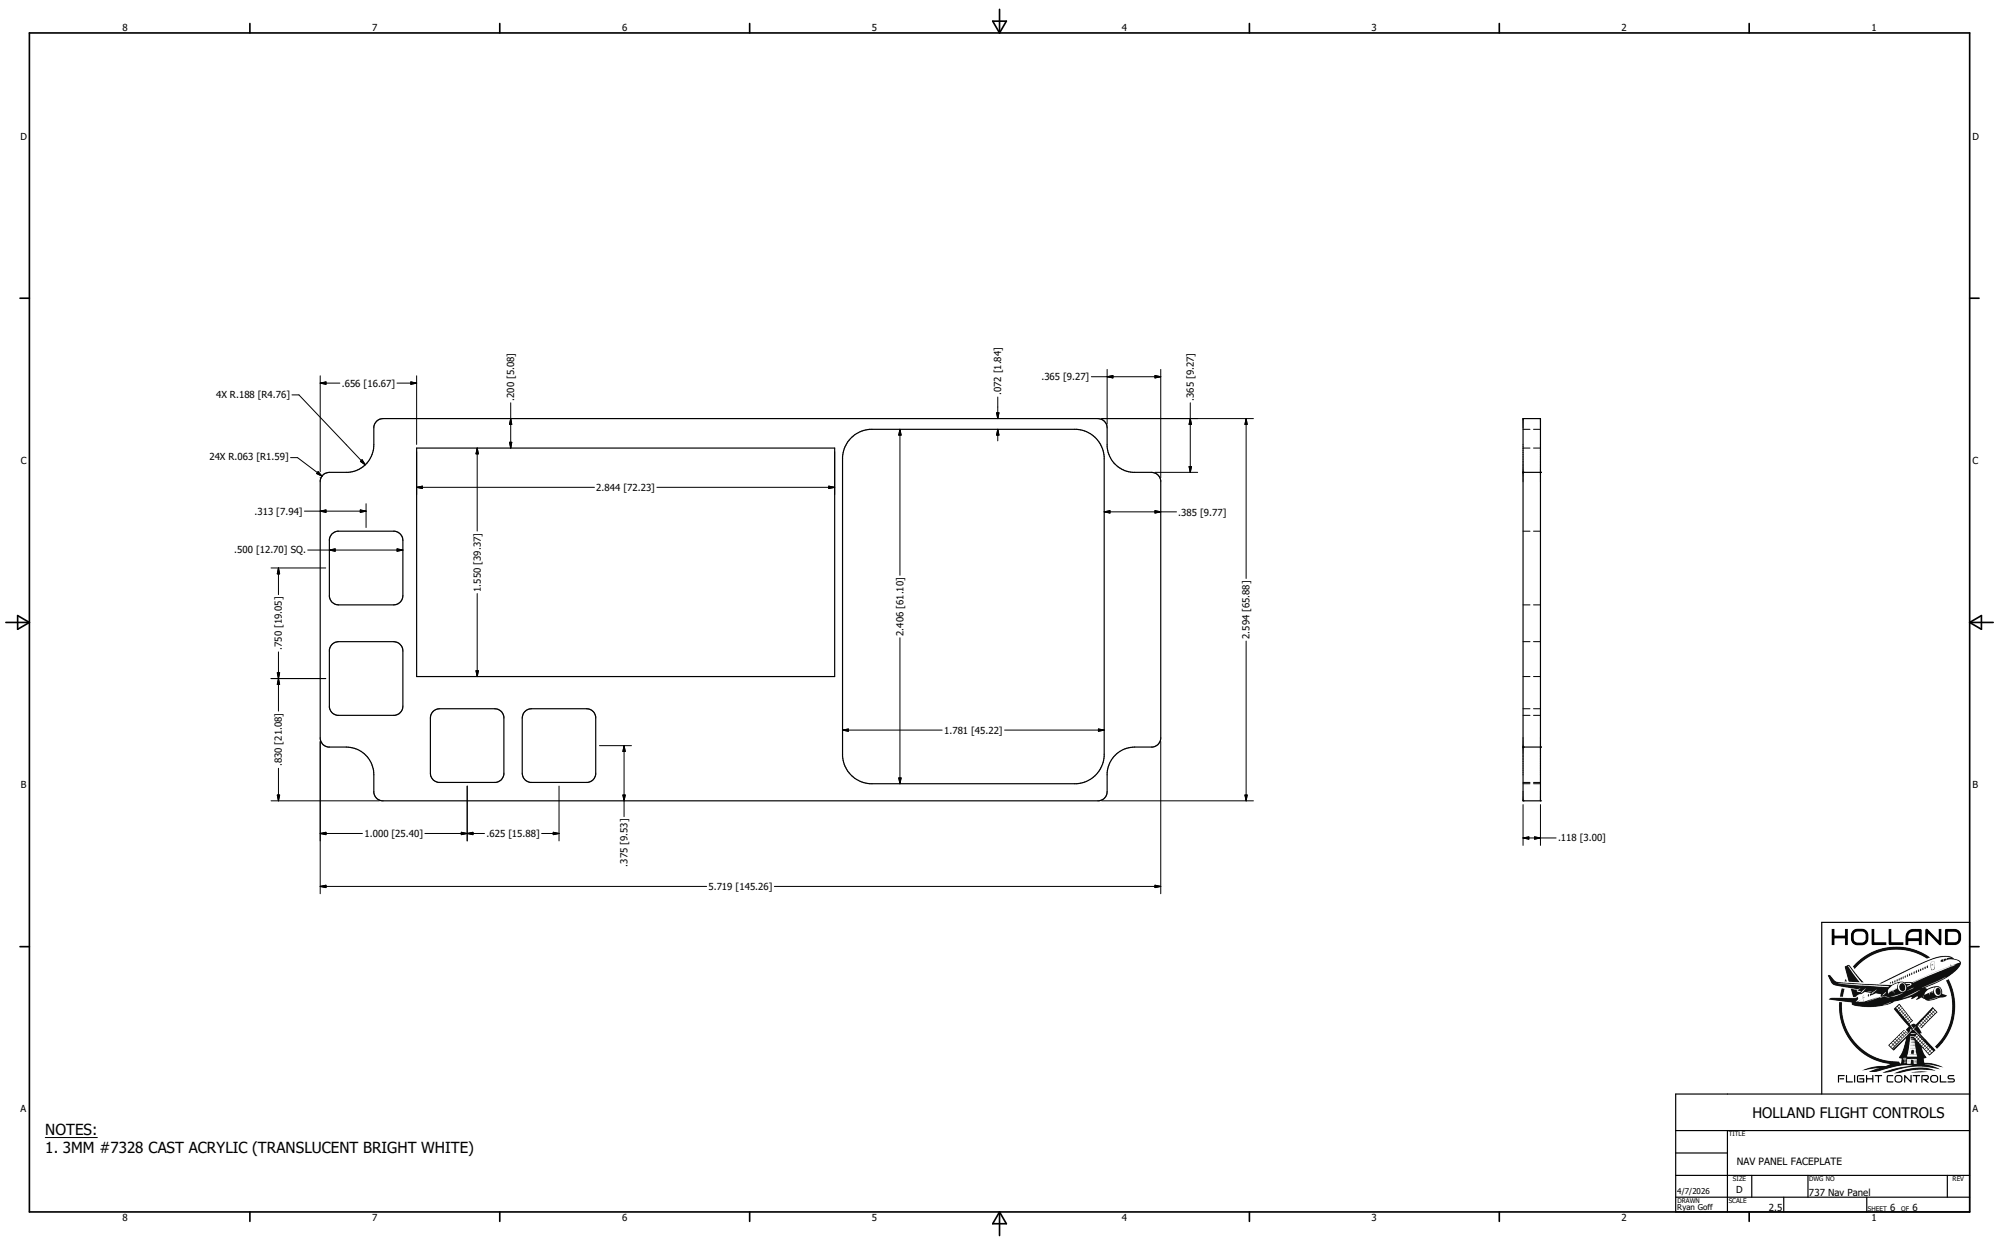
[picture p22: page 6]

NOTES:
1. 3MM #7328 CAST ACRYLIC (TRANSLUCENT BRIGHT WHITE)

HOLLAND FLIGHT CONTROLS TITLE

NAV PANEL FACEPLATE

SIZE D

2.5 SHEET 6 OF 6
